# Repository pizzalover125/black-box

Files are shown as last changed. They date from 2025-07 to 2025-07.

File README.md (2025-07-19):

# black-box
Black Box was a YSWS program ran by @lux in 2025. The premise was simple: 64 LEDs, 5 buttons, and a buzzer. It was a YSWS about limitations. I absolutely LOVED the idea, but never got around to making a Black Box. When fufillment came around, all that was shipped to participants was three breadboards, a bunch of wires, and all the parts to assemble this. I was flabberghasted. All of this money going to breadboards? I knew something had to be done. I made a PCB for #black-box. Read JOURNAL.md for a more detailed story. 

## Images
### Schematic


### PCB


### CAD
Adobe Express Background Remover


## BOM
* 1x Raspberry Pi Pico H ($5.00 from Adafruit) (https://www.adafruit.com/product/5525) 
* 20x 6mm Push Buttons ($2.50 from Adafruit) (https://www.adafruit.com/product/367)
* 1x PS1240 Piezo Buzzer ($1.50 from Adafruit) (https://www.adafruit.com/product/160)
* 1x 1.2" 8x8 LED Matrix ($3.95 from Adafruit) (https://www.adafruit.com/product/455)
**Subtotal: $19.62 (from Adafruit)**
* 1x PCB ($5.30 from JLCPCB)
**Total: 24.92**

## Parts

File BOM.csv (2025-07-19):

Quantity | Component | Price (USD) | Source | Link
1 | Raspberry Pi Pico H | 5.00 | Adafruit | https://www.adafruit.com/product/5525
20 | 6mm Push Buttons | 2.50 | Adafruit | https://www.adafruit.com/product/367
1 | PS1240 Piezo Buzzer | 1.50 | Adafruit | https://www.adafruit.com/product/160
1 | 1.2" 8x8 LED Matrix | 3.95 | Adafruit | https://www.adafruit.com/product/455
1 | PCB | 5.30 | JLCPCB
 |  | Subtotal (Adafruit) | 19.62
 |  | Total | 24.92

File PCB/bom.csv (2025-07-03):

Designator | Footprint | Quantity | Value | LCSC Part #
LS1 | XDCR_PS1240P02BT | 1 | PS1240P02BT
SW1, SW2, SW3, SW4, SW5 | SW_PUSH_6mm | 5 | SW_Push
U1 | RaspberryPi_Pico_Common_THT | 1 | Pico
U2 | LED_1088_Pin_Header | 1 | 1088AS

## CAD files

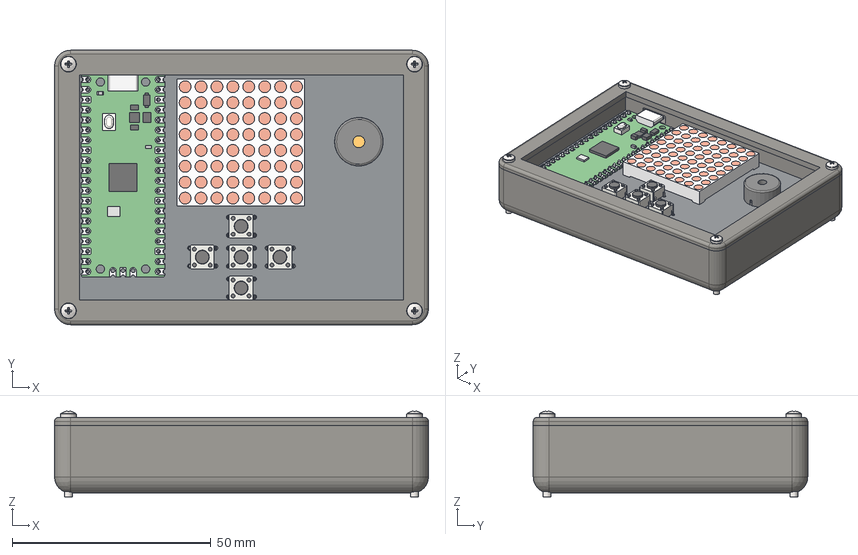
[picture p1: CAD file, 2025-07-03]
CAD/build.step
94.0 x 69.0 x 21.6 mm
PICO_assm_140121.STEP x 101
PS1240P02BT x 3
M2 x 20 Screw head x 4
SW_PUSH_6mm_1
SW_PUSH_6mm_3
Untitled_PCB
SW_PUSH_6mm_4
SW_PUSH_6mm_2
SW_PUSH_6mm

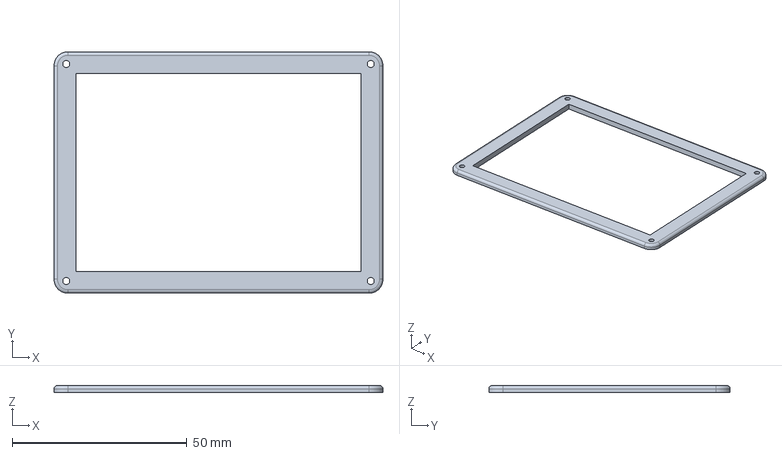
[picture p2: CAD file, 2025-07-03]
CAD/plate.step
94.0 x 69.0 x 2.00 mm

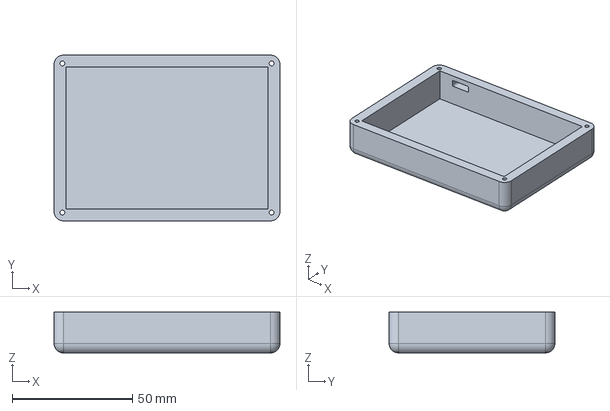
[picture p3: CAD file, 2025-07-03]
CAD/case.step
94.0 x 69.0 x 17.0 mm

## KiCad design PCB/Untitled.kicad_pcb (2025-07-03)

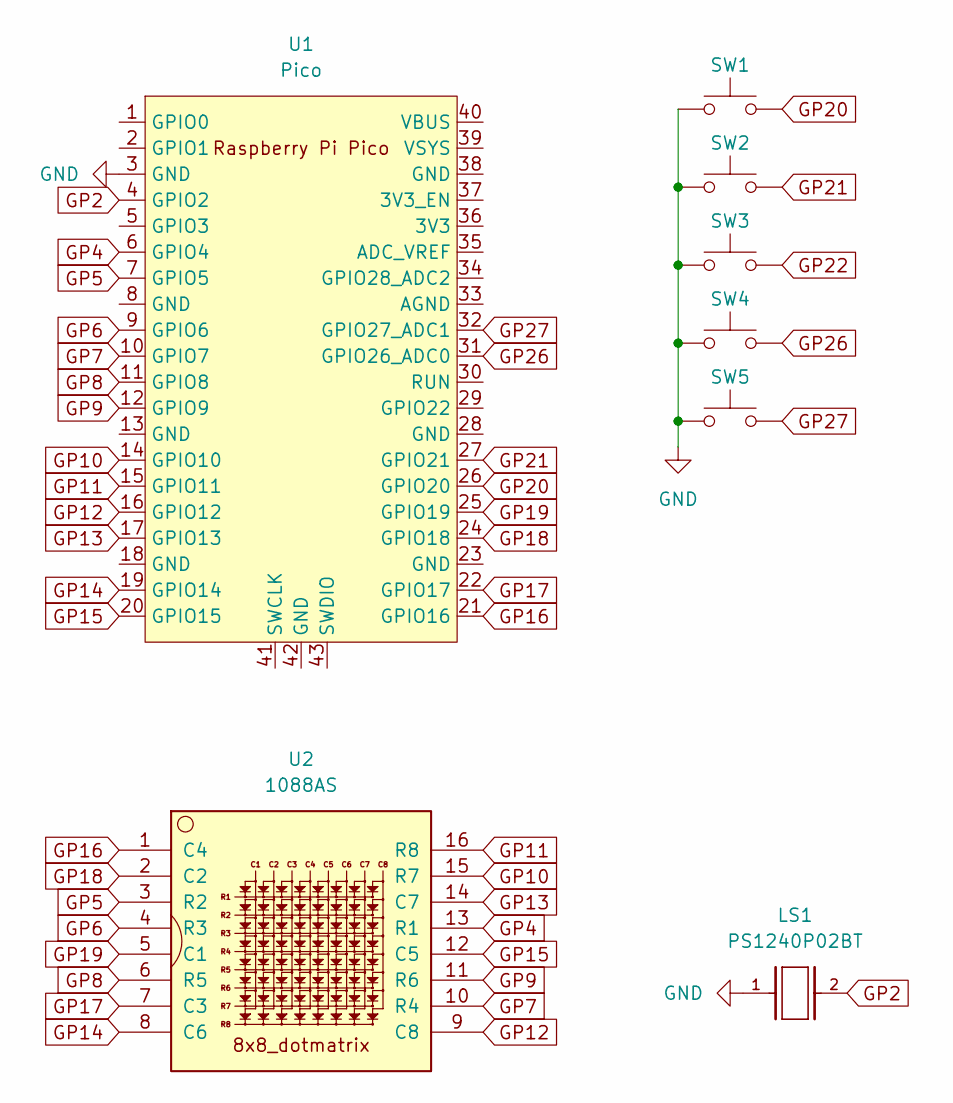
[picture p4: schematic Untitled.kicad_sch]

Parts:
LS1: PS1240P02BT; XDCR_PS1240P02BT
SW1, SW2, SW3, SW4, SW5: SW_Push; SW_PUSH_6mm
U1: Pico; RaspberryPi_Pico_Common_THT
U2: 1088AS; LED_1088_Pin_Header

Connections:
GND: LS1.1, SW1.1, SW2.1, SW3.1, SW4.1, SW5.1, U1.3 (GND)
GP2: LS1.2, U1.4 (GPIO2)
GP4: U1.6 (GPIO4), U2.13 (R1)
GP5: U1.7 (GPIO5), U2.3 (R2)
GP6: U1.9 (GPIO6), U2.4 (R3)
GP7: U1.10 (GPIO7), U2.10 (R4)
GP8: U1.11 (GPIO8), U2.6 (R5)
GP9: U1.12 (GPIO9), U2.11 (R6)
GP10: U1.14 (GPIO10), U2.15 (R7)
GP11: U1.15 (GPIO11), U2.16 (R8)
GP12: U1.16 (GPIO12), U2.9 (C8)
GP13: U1.17 (GPIO13), U2.14 (C7)
GP14: U1.19 (GPIO14), U2.8 (C6)
GP15: U1.20 (GPIO15), U2.12 (C5)
GP16: U1.21 (GPIO16), U2.1 (C4)
GP17: U1.22 (GPIO17), U2.7 (C3)
GP18: U1.24 (GPIO18), U2.2 (C2)
GP19: U1.25 (GPIO19), U2.5 (C1)
GP20: SW1.2, U1.26 (GPIO20)
GP21: SW2.2, U1.27 (GPIO21)
GP22: SW3.2
GP26: SW4.2, U1.31 (GPIO26_ADC0)
GP27: SW5.2, U1.32 (GPIO27_ADC1)

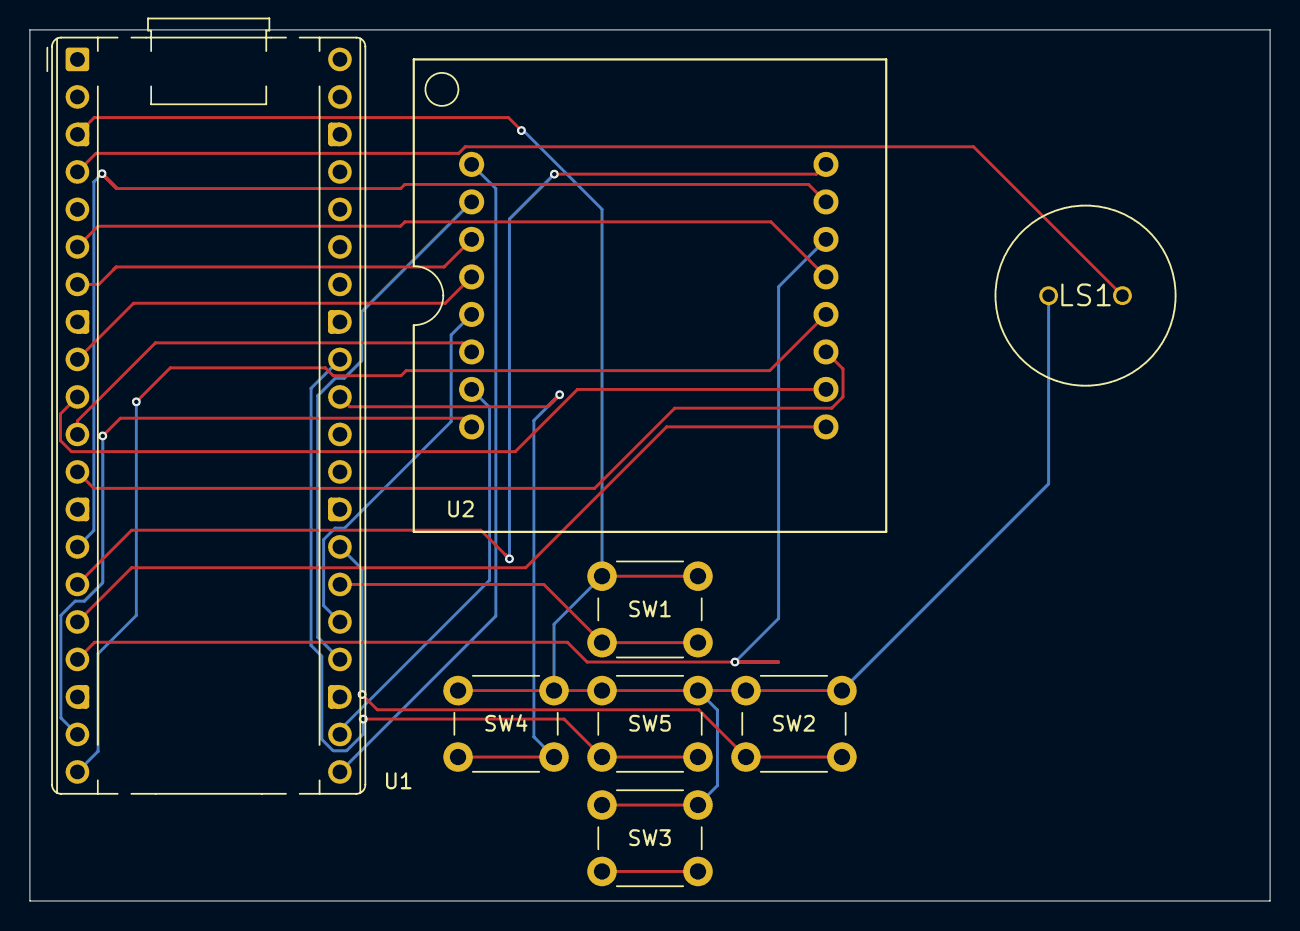
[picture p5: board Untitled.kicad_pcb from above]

Board: 2 copper layers, 84.0 x 59.0 mm, 8 parts (0 on the bottom side), 22 nets.

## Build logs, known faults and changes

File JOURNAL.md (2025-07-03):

## July 1st, 2025
When I noticed #black-box was fufilling prizes by giving everyone 3 MINI BREADBOARDS, I was perplexed to say the least. That's just so, so expensive and unprofessional. I actually really like the concept of black-box: 64 LEDs, 5 buttons, and a buzzer. Nothing more, nothing less. Simple and pleasant. The editor is also super nice and has so many features. But shipping out unpolished, expensive kits? Sounds like a disaster. I want to fix that. Maybe, I can mass produce this to make a v2. The editor should not go to waste. So... I got started.

I followed the wiring instructions in blackbox.hackclub.com/build to design the schematic. This type of project is super easy for me, as I've made far, far more complicated PCBs. However, it still took a long time to import the files (some of them wouldn't load for some reason) and to just follow the instructions. Here is what I got: 



After that, I began work on the PCB. I just wanted to get a prototype out. For this reason, it was SUPER unpolished. Everything was off-center. 


Next, I made the case. Again, super simple as I have done stuff like this before. 


## July 2nd, 2025
I showed off my work at this show n' tell call, hosted by @Goos. It was really cool seeing the other projects. When it was my turn to present, everybody liked it to an extent, but hated the fact it was off-center. Deep down, I felt the same way. Something had to be done. So... I ended up completely redesigning EVERYTHING (except the schematic, of course). At the end of this mid-life crisis /j, I got this as result for the PCB:


Finally, I had to redesign the case. All I had to do was change a couple of dimensions. I also added these somewhat random filets to make it feel a bit rounded. I went with an exposed aesthetic. Here is the final result:
Adobe Express Background Remover
